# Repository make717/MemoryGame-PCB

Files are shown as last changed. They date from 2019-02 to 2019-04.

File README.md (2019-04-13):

# MemoryGame-PCB
KiCad PCB files for custom [Make717 memory game](https://github.com/make717gh/MemoryGame) soldering badge. This badge was designed and built by members of [Make717](https://www.make717.org) for a soldering event at the [Lancaster Science Factory](https://www.lancastersciencefactory.org/) on April 27, 2019.

This badge is using the [SAMD21G](https://cdn-shop.adafruit.com/product-files/2772/atmel-42181-sam-d21_datasheet.pdf) 32-bit microcontroller running [CircuitPython](https://github.com/make717gh/circuitpython). Thank you to [Adafruit](https://www.adafruit.com). 

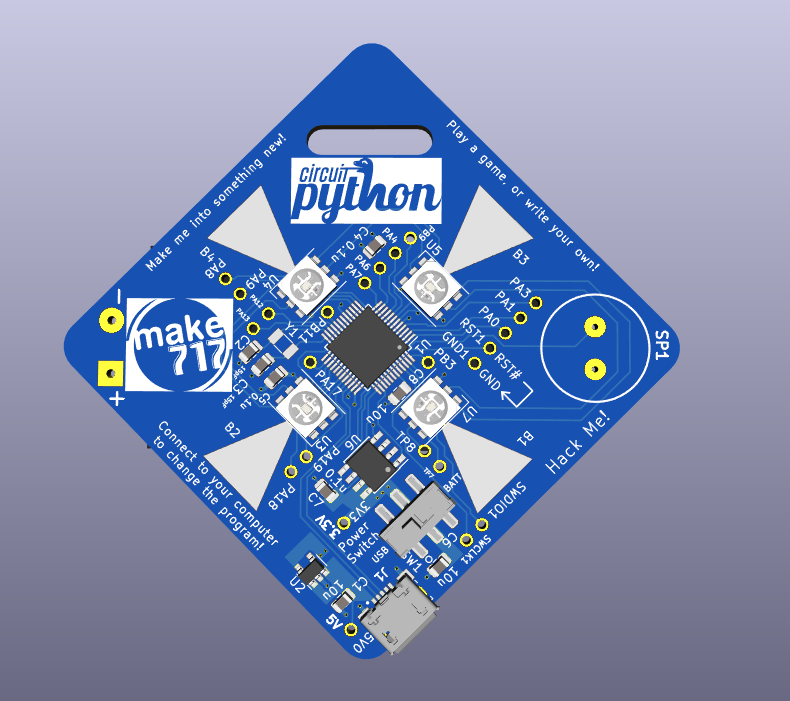
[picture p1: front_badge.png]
Make717badge


# Power
The badge is powered by either USB or two AAA batteries (*SW1* "Power Switch" can be either in *USB* or *BATT*). If using batteries, ensure they are 1.5 volts and fully charged. The badge might not power up with recharable batteries which are often rated at 1.2 volts. The USB connection goes through a voltage regulator to supply 3.3 volts to the microcontroller and other components on the board.

# Ready to Build
If you are joining us at Make717, or have all the component to build a badge, you can follow the [assembling instructions](https://github.com/make717gh/MemoryGame-PCB/blob/master/ASSEMBLING.md) which include tips on what to check if the badge is not working.

# Flashing and Firmware
You can update the firmware on the badge over USB by droping an updated UF2 image when in bootloader mode. To enter this mode, double tap the *RST1* to *GND1* while powered over USB. The drive should reappear as *MAKEBOOT* when it has entered this mode. 

It is also possible to directly program the SAMD21G18A using Serial Wire Debug (SWD). We recommend a [J-LINK](https://www.adafruit.com/product/3571) programmer or similar, connecting to *SWDIO1* (data), *SWCLK1* (clock), *GND1* (ground), and *3V3* (power). You will also need to power the board with 3.3 volts which can be done via the USB connection while programming or the *5V* pin near the USB port.

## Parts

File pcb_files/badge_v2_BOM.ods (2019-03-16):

Designator | Quantity | Designation | MFG | MFG # | Distributor | Price | Total Price | Delivery Date
U7,U3,U4,U5 | 4 | SK9822 | Colorful Pearl | SK9822 | Ebay (https://www.ebay.com/itm/20-1000PCS-SK9822-LED-5050-SMD-RGB-LED-Chip-6Pins-APA102-updated-version/372166991873) | $0.11 | $0.44 | 4-8-19
J1 | 1 | 10118193-0001LF | Amphenol FCI | 10118193-0001LF | Digi-Key | $0.30 | $0.30 | 3-11-19
SW1 | 1 | JS202011SCQN | Vimex | MSS22D18 | Ebay (https://www.ebay.com/itm/50Pcs-MSS22D18-Smd-Slide-Switch-2P2T-6-Pin-Mini-New-Ic-xt/223138255486) | $0.13 | $0.13 | 3-19-19
C1,C6,C8 | 3 | 10u | Samsung | CL21A106KQCLNNC‎ | Digi-Key | $0.04 | $0.12 | 3-11-19
C4,C5,C7 | 3 | 0.1u | Samsung | CL21F104ZBCNNNC‎ | Digi-Key | $0.02 | $0.06 | 3-11-19
U1 | 1 | ATSAMD21G18A-AUT | Microchip | ATSAMD21G18A-AU‎ | Digi-Key | $2.60 | $2.60 | 3-11-19
SP1 | 1 | PKM13EPYH4000-A0 | Murata | PKM13EPYH4000-A0 | Digi-Key | $0.34 | $0.34 | 3-11-19
U2 | 1 | MIC5504-3.3YM5-TR | Microchip | MIC5504-3.3YM5-TR | Digi-Key | $0.08 | $0.08 | 3-11-19
BH1 | 1 | Battery Holder | TrendBox | B071DK454L | Amazon (https://www.amazon.com/TrendBox-Battery-Plastic-Storage-Container/dp/B071DK454L?hvadid=226601492573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) | $0.40 | $0.40 | 3-11-19
AAA Battery | 2 | Battery |  |  | Ebay (https://www.ebay.com/itm/100-x-AAA-R03P-Batteries-Super-Heavy-Duty-UM4-1-5V-Toys-Remote-Battery-Wholesale/151643451795) | $0.18 | $0.36 | 3-11-19
Lanyard | 1 | N/A | Brady ID People | 2137-4747 | Amazon (https://www.amazon.com/gp/product/B006DMR72S/ref=ox_sc_act_title_1?smid=A259KVW6HI7JTA&psc=1) | $0.38 | $0.38 | 3-11-19
PCB | 1 | PCB with Stencil | Make717 | badge_v2a | PCBWay | $0.80 | $0.80 | 3-13-19
 |  |  |  |  |  | Total | $6.01

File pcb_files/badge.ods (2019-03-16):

Id | Designator | Package | Quantity | Designation | MFG | MFG # | Distributor | Price
1 | U7,U3,U4,U5 | LED_WS2812_PLCC6_5.0x5.0mm_P1.6mm | 4 | SK9822 | Colorful Pearl | SK9822
2 | J1 | usb | 1 | 10118193-0001LF | Amphenol FCI | 10118193-0001LF
4 | SW1 | JS202011SCQN | 1 | JS202011SCQN | Vimex | MSS22D18
6 | C1,C6 | C_0805_2012Metric | 2 | 10u | Samsung | CL21A106KQCLNNC‎
7 | C4,C5,C7 | C_0805_2012Metric | 3 | 0.1u | Samsung | CL21F104ZBCNNNC‎
8 | U1 | TQFP-48_7x7mm_P0.5mm | 1 | ATSAMD21G18A-AUT | Microchip | ATSAMD21G18A-AU‎
11 | SP1 | PKM13EPYH4002-B0 | 1 | PKM13EPYH4000-A0 | Murata | PKM13EPYH4000-A0
12 | U2 | SOT-223 | 1 | AZ1117EH-3.3TRG1 | Diodes Inc. | AZ1117EH-3.3TRG1

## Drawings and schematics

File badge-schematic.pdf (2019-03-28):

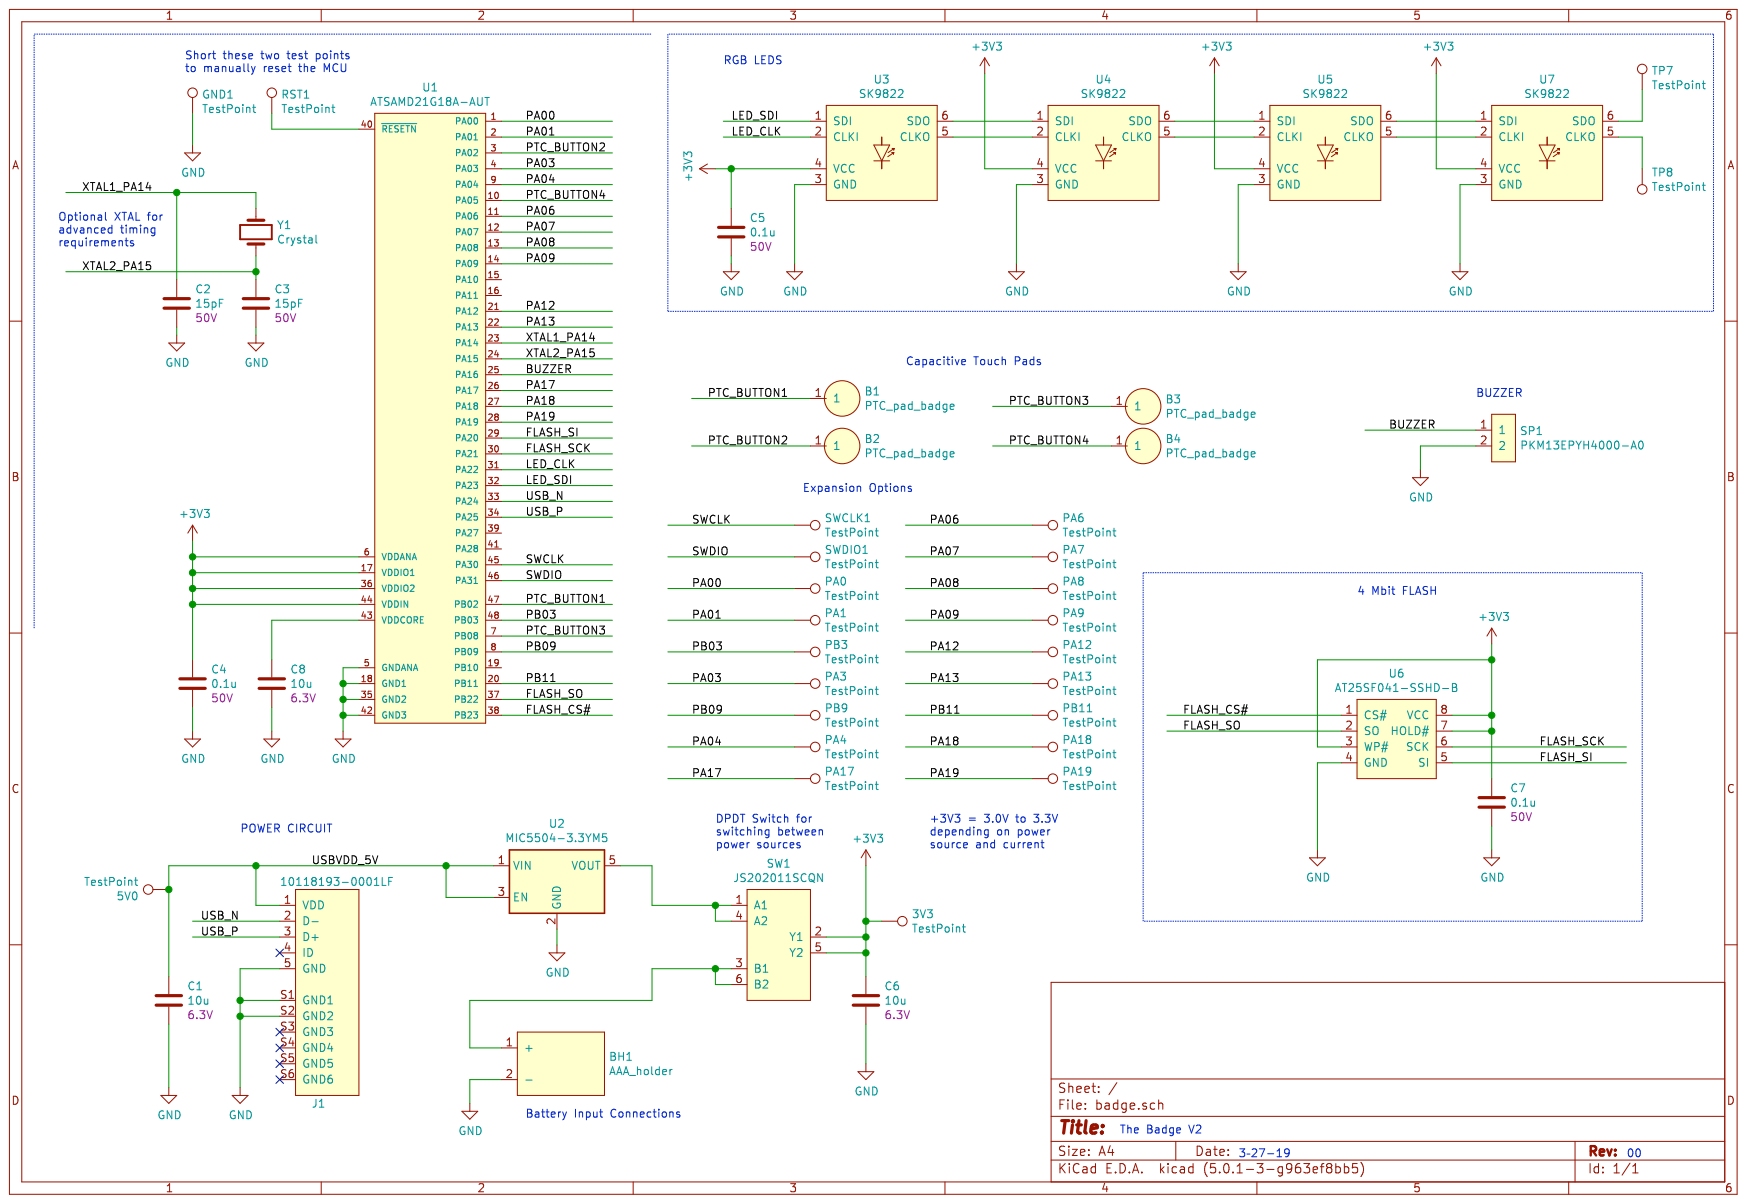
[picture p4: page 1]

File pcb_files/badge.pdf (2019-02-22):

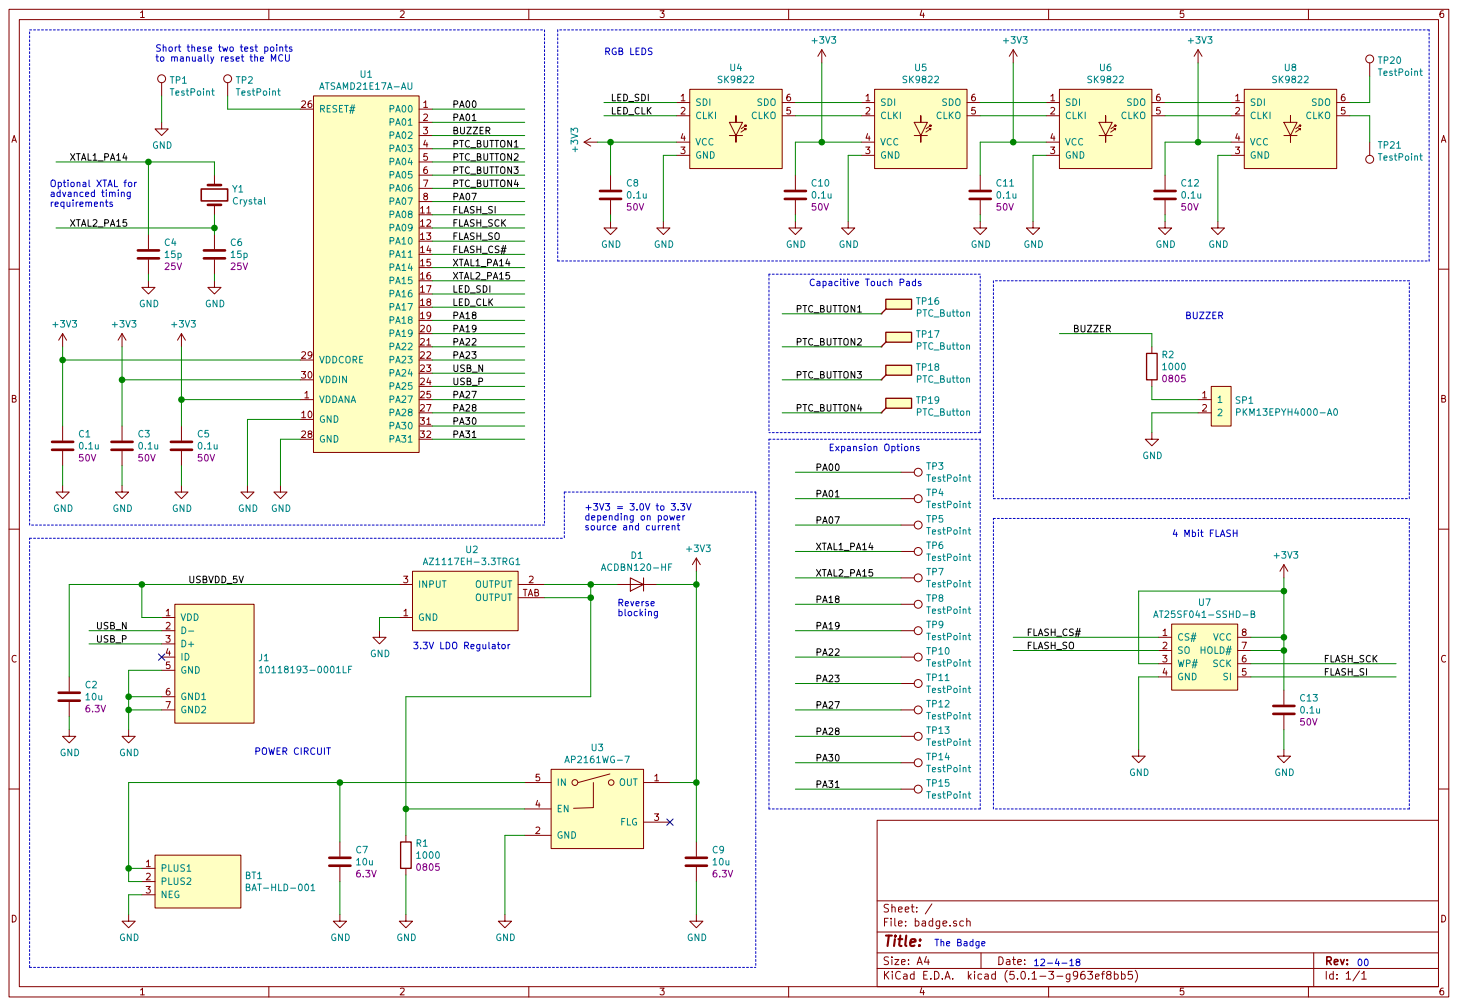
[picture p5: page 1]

Short these two test points
to manually reset the MCU

File: badge.sch Sheet: /
Id: 1/1 Title:

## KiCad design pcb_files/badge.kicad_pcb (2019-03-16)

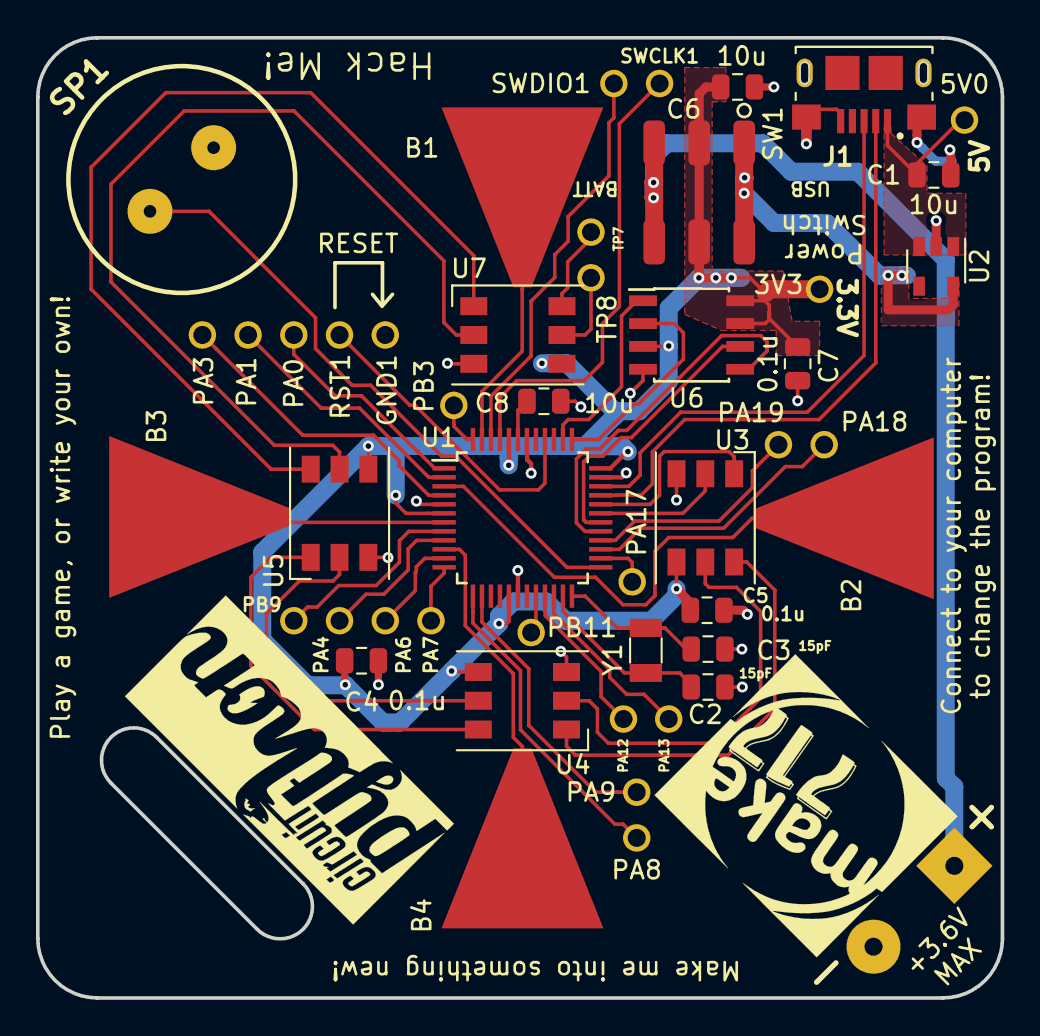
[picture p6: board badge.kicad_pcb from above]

Board: 2 copper layers, 53.6 x 53.3 mm, 48 parts (1 on the bottom side), 48 nets.

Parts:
3V3, 5V0: TestPoint; TestPoint_THTPad_D1.5mm_Drill1.0mm
B1, B2, B3, B4: PTC_pad_badge; PTC_badge
BH1: AAA_holder; aaa_battery_holder
C1, C6, C8: 10u; C_0805_2012Metric
C2, C3: 15pF; C_0805_2012Metric
C4, C5, C7: 0.1u; C_0805_2012Metric
GND1: TestPoint; TestPoint_THTPad_D1.5mm_Drill1.0mm
J1: 10118193-0001LF; usb
PA0, PA1, PA3, PA4, PA6, PA7, PA8, PA9, PA12, PA13, PA17, PA18, PA19: TestPoint; TestPoint_THTPad_D1.5mm_Drill1.0mm
PB3, PB9, PB11: TestPoint; TestPoint_THTPad_D1.5mm_Drill1.0mm
RST1: TestPoint; TestPoint_THTPad_D1.5mm_Drill1.0mm
SP1: PKM13EPYH4000-A0; PKM13EPYH4002-B0
SW1: JS202011SCQN
SWCLK1: TestPoint; TestPoint_THTPad_D1.5mm_Drill1.0mm
SWDIO1: TestPoint; TestPoint_THTPad_D1.5mm_Drill1.0mm
TP7, TP8: TestPoint; TestPoint_THTPad_D1.5mm_Drill1.0mm
U1: ATSAMD21G18A-AUT; TQFP-48_7x7mm_P0.5mm
U2: MIC5504-3.3YM5; SOT-23-5
U3, U4, U5, U7: SK9822; LED_WS2812_PLCC6_5.0x5.0mm_P1.6mm
U6: AT25SF041-SSHD-B; SOIC-8_3.9x4.9mm_P1.27mm
Y1: Crystal; Crystal_SMD_3215-2Pin_3.2x1.5mm

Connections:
+3V3: 3V3.1, C4.1, C5.1, C6.1, C7.1, SW1.2, SW1.5, U1.6, U1.17, U1.36, U1.44, U3.4, U4.4, U5.4, U6.3, U6.7, U6.8, U7.4
/BUZZER: SP1.1, U1.25
/FLASH_CS#: U1.38, U6.1
/FLASH_SCK: U1.30, U6.6
/FLASH_SI: U1.29, U6.5
/FLASH_SO: U1.37, U6.2
/LED_CLK: U1.31, U3.2
/LED_SDI: U1.32, U3.1
/PA00: PA0.1, U1.1
/PA01: PA1.1, U1.2
/PA03: PA3.1, U1.4
/PA04: PA4.1, U1.9
/PA06: PA6.1, U1.11
/PA07: PA7.1, U1.12
/PA08: PA8.1, U1.13
/PA09: PA9.1, U1.14
/PA12: PA12.1, U1.21
/PA13: PA13.1, U1.22
/PA17: PA17.1, U1.26
/PA18: PA18.1, U1.27
/PA19: PA19.1, U1.28
/PB03: PB3.1, U1.48
/PB09: PB9.1, U1.8
/PB11: PB11.1, U1.20
/PTC_BUTTON1: B1.1, U1.47
/PTC_BUTTON2: B2.1, U1.3
/PTC_BUTTON3: B3.1, U1.7
/PTC_BUTTON4: B4.1, U1.10
/SWCLK: SWCLK1.1, U1.45
/SWDIO: SWDIO1.1, U1.46
/USBVDD_5V: 5V0.1, C1.1, J1.1, U2.1, U2.3
/USB_N: J1.2, U1.33
/USB_P: J1.3, U1.34
/XTAL1_PA14: C2.1, U1.23, Y1.1
/XTAL2_PA15: C3.1, U1.24, Y1.2
GND: BH1.2, C1.2, C2.2, C3.2, C4.2, C5.2, C6.2, C7.2, C8.2, GND1.1, J1.5, J1.S1, J1.S2, SP1.2, U1.5, U1.18, U1.35, U1.42, U2.2, U3.3, U4.3, U5.3, U6.4, U7.3
unnamed: BH1.1, SW1.3, SW1.6
unnamed: C8.1, U1.43
unnamed: RST1.1, U1.40
unnamed: SW1.1, SW1.4, U2.5
unnamed: TP7.1, U7.6
unnamed: TP8.1, U7.5
unnamed: U3.5, U4.2
unnamed: U3.6, U4.1
unnamed: U4.5, U5.2
unnamed: U4.6, U5.1
unnamed: U5.5, U7.2
unnamed: U5.6, U7.1

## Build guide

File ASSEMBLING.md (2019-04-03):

# Assembly Instructions

The following instructions is for building the badges, but leaving the buzzer and battery unattached. These two components will be soldered on by students as part of their lesson.

Parts list:
 * one SAMD21G18A 48 pin micro-controller (pre-programmed)
 * four DotStar SK9822 LEDs
 * three 10u capacitors (0805 size)
 * three 0.1u capacitors (0805 size)
 * one microUSB port
 * one MIC5504 3.3 volt regulator
 * one power switch

Here's a rendering of the final populated badge
Make717badge

Note: We will NOT be populating U6, C2, C3, or SP1 in these instructions

# Hand Soldering instructions

Start with micro-controller (U1). If you're at Make717, use one that has already been flashed with a bootloader. This will make things easier to test and won't require soldering on an additional 4 pins.
 * Make sure to align the chip's dot with the "U1" marking on the board!

Attach the USB port (J1) to the edge of the board. Solder on the large pads on the side, then the 5 leads on the back.
  * Make sure this sits flat on the board before soldering the leads.

Solder on all 6 pads for the 4 DotStar LEDs. 
 * The tiny triangle cut out needs to point towards the "Ux" marking on the board (U3, U4, U5, and U7)

Solder on the 5 legs of the voltage regulator (U2)

There are two different sets of capacitors for the board ("10u" and "0.1u"), make sure to use the correct values which are labeled on the board. Also there are additional pads on the board that will NOT get populated. These are for expansions that can be added later.These capacitors are not polarized, so can face either direction. 

 * Start with the "10u" values which go in 3 places on the board (C1, C6, C8). Check your micro-controller pins after C8 since these are near by.

 * Then solder the "0.1u" capacitors in the 3 places on the board (C4, C5, C7)

Finally add the switch (SW1) near the USB port. This can face either direction.

# QA Testing

Now it's time to test the board. Plug in the USB port power up the system. You should see all 4 leds light up and change color.

If nothing happens after 5 seconds, remove power and feel the micro-controller and voltage regulator. If either are warm or hot, first check the board for any shorts and that components are in the correct orientation.

If only a few LEDs light up.
 * Check the orenitation of the LEDs. Are the triangle cutout facing the labels on the silk-screen (U3, U4, U5, and U7)
 * Is there enough solder on each of the 6 pads from the LED?
 * Is there too much solder on any pad causeing them to bridge?
 * If this was done in the reflow oven, they may have been over baked

If there are no lights at all, here's a few things to try.
 * Press fit a buzzer to SP1, and press any triangle button a few times. Do you hear any beeping? If so, the code is running and it is most likely an issue with the LEDs.
 * Plug in the USB port to a computer. Does any new drive show up? If so, then the USB port, regulator, and micro-controller are probably fine.
 * Use a multimeter and check the "GND1" and "5V0" pins while plugged into USB power. This should read close to 5 volts. If not, check the USB port.
 * Use a multimeter and check the "GND1" and "3V3" pins while plugged into USB power. It should read close to 3.3 volts. If not, check the regulator, and capacitors (C1, C6, C7).

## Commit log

2019-02-22 PDF of schematic and top board
2019-03-16 including kicad files
    [badge-B.Cu.gbr, badge-B.Mask.gbr, badge-B.SilkS.gbr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]
2019-03-20 Update power and firmware info
2019-04-03 Updated Pin values for final board design
2019-04-03 Adding heat check
2019-04-03 Update ASSEMBLING.md
    Added power switch to bullet list
